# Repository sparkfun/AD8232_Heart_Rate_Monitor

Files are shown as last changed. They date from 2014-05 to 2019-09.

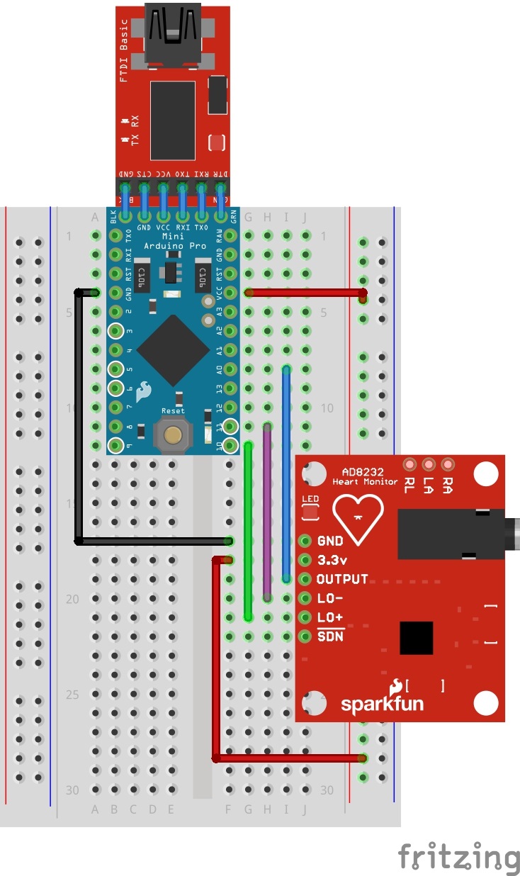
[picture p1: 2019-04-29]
Fritzing/AD8232_Heart_Rate_Monitor_Demo_bb_Fritzing_Corrected.jpg

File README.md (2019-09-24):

SparkFun AD8232 Single Lead Heart Rate Monitor
-------------------

AD8232 Breakout Board (https://www.sparkfun.com/products/12650)

[*AD8232 Single Lead Heart Rate Monitor (SEN-12650)*](https://www.sparkfun.com/products/12650)

The AD8232 is a neat little chip used to measure the electrical activity of the heart. This electrical activity can be charted as an ECG or Electrocardiogram. [Electrocardiography](http://en.wikipedia.org/wiki/Electrocardiography) is used to help diagnose various heart conditions. [The datasheet can be found here.](https://cdn.sparkfun.com/datasheets/Sensors/Biometric/AD8232.pdf)

This part was created in Eagle v6.5.0. 

Repository Contents
-------------------

* **/Fritzing** - Fritzing Example wiring images
* **/Hardware** - All Eagle design files (.brd, .sch)
* **/Production** - production panel files
* **/Software** - Demo program files for hookup guide

Documentation
--------------
* **[Hookup Guide](https://learn.sparkfun.com/tutorials/ad8232-heart-rate-monitor-hookup-guide/)** - Basic hookup guide AD8232 heart rate monitor.

Version History
---------------
* [v10](https://github.com/sparkfun/AD8232_Heart_Rate_Monitor/tree/v10) Initial Release

License Information
-------------------
The hardware is released under [Creative Commons Share-alike 3.0](http://creativecommons.org/licenses/by-sa/3.0/).  
All other code is open source so please feel free to do anything you want with it; you buy me a beer if you use this and we meet someday ([Beerware license](http://en.wikipedia.org/wiki/Beerware)).

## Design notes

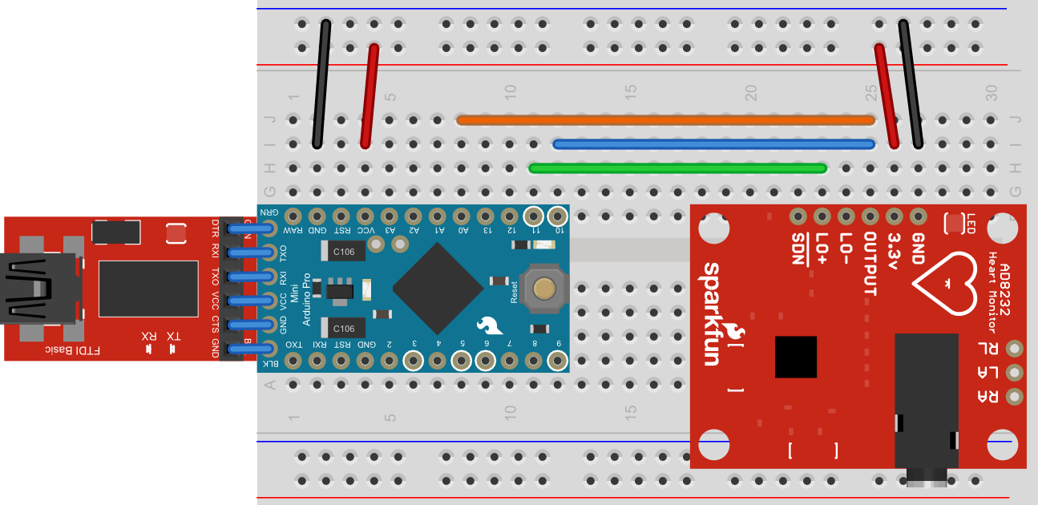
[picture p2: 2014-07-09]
Fritzing/Ad8232_Fritzing_Diagram.png

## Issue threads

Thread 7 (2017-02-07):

Not compatible with Processing 3.2.4

SSJJYY, 2017-02-07:
These codes cannot be operated on Processing 3.2.4 successfully. Only can on Processing 2.2.1.
Problems happens when you run it, it shows a blank display screen.
Can you update codes for version 3.2.4?
Thank you a lot.

paulio23, 2017-02-12:
Second that.

Fieryfire, 2017-02-13:
third that

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

mctosimaitb, 2017-02-16:
agree :)

ShubhaM220, 2017-03-08:
why is it not working on processing 3.2.4 ??

rubueh, 2017-04-30:
Ive made a pull request for the updated version of the heart rate monitor but have not gotten a response from Sparkfun. Here are some proposed changes for the code of the heart rate monitor, the old code could only function in the second version of Processing. The proposed changes now work for the newest version (3.3.2). I figured other individuals could benefit from this and help them get their project done faster and with a lot less headaches.

Side-Note

The only hiccup I encountered in modifying the code and comparing it to the old one's readings was that when it is supposed to be flat-line there is a negative charge that is registered, which was not there when run in Processing v2.
-RKB

Also let me know how it works for you.

//-----------------------------------New Code for Processing 3.2.+------------------//

/*
*  All rights reserved to the original creators.
*/

import processing.serial.*;

Serial myPort;
int xPos = 1;
float height_old = 0;
float height_new = 0;
float inByte = 0;

void setup () {
  //Window Size
  size(1080, 500);

  // List serial ports
  println(Serial.list());
  myPort = new Serial(this, Serial.list()[0], 9600);
  myPort.bufferUntil('\n');

  //Background
  background(255);

  fill(color(0,0,0));
  text("Heart Rate Monitor v1.0", 10, 10);
}

void draw () {

     inByte = map(inByte, 0, 1023, 0, height);
     height_new = height - inByte;
     line(xPos - 1, height_old, xPos, height_new);
     height_old = height_new;

      if (xPos >= width) {
        xPos = 0;
        background(255);
      }
      else {
        xPos++;
      }
}

void serialEvent (Serial myPort) {
  // get the ASCII string:
  String inString = myPort.readStringUntil('\n');

  if (inString != null) {
    // trim off any whitespace:
    inString = trim(inString);

    if (inString.equals("!")) {
      stroke(0, 0, 255);
      inByte = 512;
    }
    else {
      stroke(255, 0, 0);
      inByte = float(inString);
     }
  }
}

rubueh, 2017-04-30:
`//-----------------------------------New Code for Processing 3.2.+------------------//

/*
*  All rights reserved to the original creators.
*/

import processing.serial.*;

Serial myPort;
int xPos = 1;
float height_old = 0;
float height_new = 0;
float inByte = 0;

void setup () {
  //Window Size
  size(1080, 500);

  // List serial ports
  println(Serial.list());
  myPort = new Serial(this, Serial.list()[0], 9600);
  myPort.bufferUntil('\n');

  //Background
  background(255);

  fill(color(0,0,0));
  text("Heart Rate Monitor v1.0", 10, 10);
}

void draw () {

     inByte = map(inByte, 0, 1023, 0, height);
     height_new = height - inByte;
     line(xPos - 1, height_old, xPos, height_new);
     height_old = height_new;

      if (xPos >= width) {
        xPos = 0;
        background(255);
      }
      else {
        xPos++;
      }
}

void serialEvent (Serial myPort) {
  // get the ASCII string:
  String inString = myPort.readStringUntil('\n');

  if (inString != null) {
    // trim off any whitespace:
    inString = trim(inString);

    if (inString.equals("!")) {
      stroke(0, 0, 255);
      inByte = 512;
    }
    else {
      stroke(255, 0, 0);
      inByte = float(inString);
     }
  }
}`

XDTZ, 2017-05-01:
@rubueh I felt very lucky finishing my wiring and immediately finding your fix no longer than a day after you posted!
The code does work for me. However it seems serial plotter produce graph more clear than this. Thanks anyway!

rubueh, 2017-05-01:
@XDTZ I am glad the code was able to help and for getting back on how it works for you. If I can recommend something, while working on the wiring and programming I noticed my data was wonky while I had my charger plugged in to my laptop during testing. I then removed the charger and voila, it worked. So just double check your wiring or if you have an external power source that may be causing the interference, see if you can mend it. You may not need any extra items. Best of luck though!

marziacescon, 2017-05-31:
Hi!

I'm still having the blank screen problem, despite I'm running the fixed script proposed here..I don't know what I'm doing wrong! I feel discouraged. Any chance I could get any help here?

Thanks heaps!
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

Fieryfire, 2017-05-31:
Hi,

Do you see, if there is transmission through serial monitor?

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

marziacescon, 2017-06-01:
Hi! Thanks for your prompt reply! I'm new to this so not experienced at all!

How do you see if you get transmission? I mean: I can plot things on the
screen if I want to..just I can't visualize the ECG...

Marzia

On Wed, May 31, 2017 at 3:02 PM, Vivin Arikkudil <notifications@github.com>
wrote:

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

marziacescon, 2017-06-01:
Hi,

got it. I tried to modify that in order to allow communication, but nothing
happens still...

The ports are the following:

/dev/cu.Bluetooth-Incoming-Port /dev/cu.Bluetooth-Modem
/dev/cu.Cons-SerialPort
/dev/cu.usbserial-A904MJ7W /dev/tty.Bluetooth-Incoming-Port
/dev/tty.Bluetooth-Modem
/dev/tty.Cons-SerialPort /dev/tty.usbserial-A904MJ7W

Anything wrong in there?

Thanks again!

Marzia

On Wed, May 31, 2017 at 4:57 PM, Russell Buehling <notifications@github.com>
wrote:

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

marziacescon, 2017-06-01:
When I change port, I get the following error message (attached
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
)

rubueh, 2017-06-01:
@marziacescon
Hmmm first try checking all your wiring is correct, connect the ECG leads, run the sketch and see if can get a signal (even if its ugly one) from the leads just to make sure they are making contact and the wiring is correctly routing the signals. The other problem may be that if you have the Arduino program open, it is taking control of that port first to communicate with the Arduino itself. If so, just exit out, if not try to see what is taking up the communications port channel.

rubueh, 2017-06-01:
@marziacescon
I just realized your COM list simply looks different, so for every `/dev/` item you see, that is a different port. So the port you are wanting to communicate through may actually be `Serial.list()[5]` .

Fieryfire, 2017-06-02:
I think it says port busy because you are opening the serial monitor from
the arduino IDE as well. Let go of the the serial monitor and just let the
code from processing run

On Thu, Jun 1, 2017 at 5:21 PM, Russell Buehling <notifications@github.com>
wrote:

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

njay96, 2017-06-04:
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
@rubueh im so happy when ur code work for me, thank you. but, my result so noisy. how to calibrate it? or it because wrong placement of the sensor. i so confused if it by sensor placement, im affraid if i not correctly put that sensor. sorry my english so bad. anyway, thank you!

marziacescon, 2017-06-04:
Hi!

Thank you for your suggestions.

I'm afraid to say, I still have the same problem.

* I'm letting the code from Processing only run (no Arduino)
* I have identified the correct port, i.e., I don't get the "port busy"
message anymore.

But I still have only a blank screen...like no signals is going through.
I've check the wiring as well and it seems correct...What shall I do now?

Thank you in advance!

Marzia

On Fri, Jun 2, 2017 at 9:09 AM, Vivin Arikkudil <notifications@github.com>
wrote:

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

marziacescon, 2017-06-04:
I'm thinking that maybe the AD8232 is faulty....

Marzia

On Fri, Jun 2, 2017 at 9:09 AM, Vivin Arikkudil <notifications@github.com>
wrote:

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

rubueh, 2017-06-04:
@marziacescon

I'm thinking it might be as well, if not ask someone else to double check everything as a last resort and no problem, I really do hope you can get it to work.

marziacescon, 2017-06-04:
I do hope it as well.

I got already someone checking the wiring : it seems all is good. So i
think the sensor might be faulty.

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

Fieryfire, 2017-06-04:
Does the serial port from the arduino IDE run any values to the the monitor?

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

marziacescon, 2017-06-05:
Actually not. No numbers. It's so frustrating!

Marzia

On Sun, Jun 4, 2017 at 11:33 PM, Vivin Arikkudil <notifications@github.com>
wrote:

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

Fieryfire, 2017-06-05:
Using a multimeter, are you able to get any sort of readings from the
analog output?

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

marziacescon, 2017-06-05:
Hi!

I'm going to borrow one as soon as I can.

In the meantime, I checked if the Arduino and Processing were able to
communicate. I used the following scripts:

***arduino***
**************
void setup()
{
//initialize serial communications at a 9600 baud rate
Serial.begin(9600);
}

void loop()
{
//send 'Hello, world!' over the serial port
Serial.println("Hello, world!");
//wait 100 milliseconds so we don't drive ourselves crazy
delay(100);
}

***processing***
******************
import processing.serial.*;
Serial myPort;  // Create object from Serial class
String val;     // Data received from the serial port
void setup()
{
  // I know that the first port in the serial list on my mac
  // is Serial.list()[0].
  // On Windows machines, this generally opens COM1.
  // Open whatever port is the one you're using.
  String portName = Serial.list()[0]; //change the 0 to a 1 or 2 etc. to
match your port
  myPort = new Serial(this, portName, 9600);
}
void draw()
{
  if ( myPort.available() > 0)
  {  // If data is available,
  val = myPort.readStringUntil('\n');         // read it and store it in val
  }
println(val); //print it out in the console
}

****

And what I get out printed in the console is:
null
null
null
...

Do it seems that the Arduino is not talking to processing..maybe why I
don't get any signal displayed. I swear, I followed the instructions
literally and I'm not getting it to work! I thought I was going to learn
things, instead I'm getting demoralised.

Marzia

On Mon, Jun 5, 2017 at 7:12 PM, Vivin Arikkudil <notifications@github.com>
wrote:

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

marziacescon, 2017-06-05:
And this is what I get on the serial monitor
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

Fieryfire, 2017-06-06:
Lets trouble shoot it step by step, the serial terminal from the arduino
IDE shows you the above results? am i correct? it means there is something
wrong from the arduino side itself.

1)Try the code using another system, windows (preferably?)
2)set the port of the arduino to be the same as the one in serial monitor.
3) Show more screenshots on your setup and lets see whats going.

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

marziacescon, 2017-06-06:
Let's do it. I really appreciate your patience! Thanks.

So:
1) I have tried the code on a Windows machine
2) The port of the Arduino is the same of the serial monitor, i.e., COM3 (see pics)
3) I am attaching some pics of the results and the setup.

Hopefully we'll be able to sort things out.
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

Fieryfire, 2017-06-06:
1) Try just outputing the hello world alone to serial. Show the result. If
the basic hello world serial out fails to work. You should first
troubleshoot this stage.
2) From the circuit wiring . Make sure to connect output of AD8232 to A0 of
arduino board. Also is the arduino a 3.3v or a 5v??? Because the AD8232 is
not 5V tolerant.
3) Make sure that when the FTDI is connected in the right direction, VCC
->VCC GND to GND,etc... Share the the pin layout of the arduino you are
using.

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

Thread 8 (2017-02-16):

Classify Wave into PQRST

mctosimaitb, 2017-02-16:
Hi, i just have an idea. What if the wave is classified into PQRST wave intervals, such as 'p wave', 'QRS Complex', and 't wave', etc. The goal is that the system can recognize that there are abnormalities of the heart such as heart attacks. Do you have a way to do that?

Fieryfire, 2017-02-16:
Hi Yes, this can be done by adding elements to the software. But do realize
that this isnt completely medically accurate. and we would need to use
medical grade equipments. This is more for hobbyists to play around with
heart rates

On Thu, Feb 16, 2017 at 6:27 AM, Martin Manullang <notifications@github.com>
wrote:

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

mctosimaitb, 2017-04-09:
could u tell me, what is the lowest number and the highest number that displayed in serial monitor when using ad8232 ?

I just want to imagine how to implement those number into ecg block paper..

Grahldg, 2018-07-16:
Hello mctosimaitb,

These values can vary significantly depending on where the electrodes are connected and from person to person.  It may be possible to normalize the data and use algorithms to identify different wave forms, but that is beyond the scope of the example provided here.  You might find the [datasheet](https://cdn.sparkfun.com/datasheets/Sensors/Biometric/AD8232.pdf) helpful.  In addition our [Technical Support Team](https://www.sparkfun.com/technical_assistance) can help with any further questions you may have.

Thanks,
Sam

Closed 2018-07-16.

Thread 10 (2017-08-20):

Calculating BPM

beingmachine, 2017-08-20:
Hello,
I have https://www.sparkfun.com/products/12650 AD8232 board, from which i can use to plot heart rate PQRST data, however  i can't see code for calculating BPM from the peak like the pulse sensor code do.

How can i calculate BPM with this board

I am getting this output at my Serial Plotter in Arduino..

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

Please help

Thank you

jawhra, 2017-12-16:
Hello,
please I am a student and I am working on the same project could you help me to get the same output , I really need the correct code .
Thanks ,I appreciate your help .

beingmachine, 2017-12-16:
Hello Jawhra,
Can you post your code.? and what you want to achieve ,Of course i will help you with this.

Grahldg, 2018-07-16:
BPM calculation example has been added to the Processing sketch [here](https://github.com/sparkfun/AD8232_Heart_Rate_Monitor/blob/master/Software/Heart_Rate_Display_Processing/Heart_Rate_Display/Heart_Rate_Display.pde).

Chininha, 2020-10-01:
@Grahldg Do you if this code of the Programming that you sent is compatible with this code:

`void setup() {
// initialize the serial communication:
Serial.begin(9600);
pinMode(10, INPUT); // Setup for leads off detection LO +
pinMode(11, INPUT); // Setup for leads off detection LO -

}

void loop() {

if((digitalRead(10) == 1)||(digitalRead(11) == 1)){
Serial.println('!');
}
else{
// send the value of analog input 0:
Serial.println(analogRead(A1));
}
//Wait for a bit to keep serial data from saturating
delay(10);
}`

Chininha, 2020-10-01:
I'm doing a project with the sensor AD8232 and I want to see the BMP, but this kind of sensor doesn't do it. Do you know if there is a way to do it?

Closed 2018-07-16.

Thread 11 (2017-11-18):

Sensor returning only '!'

MatheusCastilho2, 2017-11-18:
Hi, everyone.  I need this project for 3 days....

In condition below always return '!'

if ((digitalRead (10) == 1) || (digitalRead (11) == 1))
  { Serial.println ('!'); }
  else
  {
    Serial.println(analogRead (A0));

    }
    delay (1);

How I resolve this?

harpekar, 2018-04-15:
I have filed an issue to fix this (#12).

Grahldg, 2018-07-16:
I was unable to duplicate this issue with the circuit described in the hookup guide.  If you are having issues in the future and need more immediate assistance, please contact our [Technical Support Team](https://www.sparkfun.com/technical_assistance).

Closed 2018-07-16.

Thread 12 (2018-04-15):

SDN Pin missing from initialization

harpekar, 2018-04-15:
The SDN pin must be pulled high in order for the board to not be put into Shutdown mode, as stated in the [datasheet](http://www.analog.com/media/en/technical-documentation/data-sheets/AD8232.pdf) on page 19.

Recommend adding

```c++
pinMode(SDNBAR, INPUT);
digitalWrite(SDNBAR, HIGH);
```

in `setup()`, with SDNBAR being the Arduino pin that indexes SDN.

vredzhepov, 2018-05-30:
The SDN pin has been already pulled up by R15 so there's no need to pull it up in code.

Grahldg, 2018-07-16:
Thank you for your suggestion.  This does not seem to affect the functionality of the circuit described in the hookup guide.  If you are still having issues with this and have further questions, please contact our [Technical Support Team](https://www.sparkfun.com/technical_assistance).

Closed 2018-07-16.

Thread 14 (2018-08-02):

Sampling rate

DominiqueMakowski, 2018-08-02:
Hey, I do have a question and didn't find the answer in the data sheet.

What is the default / maximum sampling rate with which we can acquire ECG with this?

Thanks

Fieryfire, 2018-08-02:
You essentially find the bandwidth of the ECG signal and multiply by 10. So
you have 40Hz bandwidth. And with 400Hz set as sampling rate. You should be
good to go

On Thu, Aug 2, 2018 at 4:08 PM, Dominique Makowski <notifications@github.com
> wrote:

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

Fieryfire, 2018-08-03:
The AD8232 is only a signal conditioner. The output from it is analog. It
is upto you to use a micro controller with an ADC to be able to sample the
analog data
For ex. using an arduino can get the job done

On Thu, Aug 2, 2018 at 6:23 PM, Dominique Makowski <notifications@github.com
> wrote:

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

DominiqueMakowski, 2018-08-03:
Ok i got it  :)

Closed 2018-08-03.

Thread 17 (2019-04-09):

Processing about AD8232

Crazychaochao, 2019-04-09:
When i use the code of AD8232 -Heart_Rate_Display,it got a problem like this "**ArrayIndexOutOfBoundsException: 2**"
the error code is   " myPort = new Serial(this, Serial.list()[2], 9600); "
I have try to modify it,for example  0,1,2.my computer COM is 3,but it doesn’t matter

Crazychaochao, 2019-04-09:
I don't know if anyone can help me

yongjun94, 2019-04-12:
How about change your code like this?
I solved the same problem. using this.

--------------------------------------------------------
Before code
  myPort = new Serial(this, Serial.list()[2], 9600);

After code
  myPort = new Serial(this, Serial.list()[0], 9600);

Crazychaochao, 2019-04-12:
Sincerely thanks! I have solved the problem by another way.
I will get back to you later on how i solved it ,because now it's got a new problem.So embarrassing!
My English is limited,thanks again

------------------ 原始邮件 ------------------
发件人: "yongjun94"<notifications@github.com>;
发送时间: 2019年4月12日(星期五) 中午1:54
收件人: "sparkfun/AD8232_Heart_Rate_Monitor"<AD8232_Heart_Rate_Monitor@noreply.github.com>;
抄送: "邓新潮"<838338194@qq.com>; "Author"<author@noreply.github.com>;
主题: Re: [sparkfun/AD8232_Heart_Rate_Monitor] Processing about AD8232(#17)

How about change your code like this?
 I solved the same problem. using this.

Before code
 myPort = new Serial(this, Serial.list()[2], 9600);

After code
 myPort = new Serial(this, Serial.list()[0], 9600);

—
You are receiving this because you authored the thread.
Reply to this email directly, view it on GitHub, or mute the thread.

Crazychaochao, 2019-04-21:
`import processing.serial.*;

  Serial myPort;        // The serial port
  int xPos = 1;         // horizontal position of the graph
  float inByte = 0;

  int beat_old = 0;
  int BPM = 0;
  int beatIndex;
  float[] beats = new float[500];  // Used to calculate average BPM

  void setup () {
    // set the window size:
    size(600, 700);

    // List all the available serial ports
    // if using Processing 2.1 or later, use Serial.printArray()
    println(Serial.list());

    // I know that the first port in the serial list on my Mac is always my
    // Arduino, so I open Serial.list()[0].
    // Open whatever port is the one you're using.
    myPort = new Serial(this, Serial.list()[0], 9600);

    // don't generate a serialEvent() unless you get a newline character:
    myPort.bufferUntil('\n');

    // set initial background:
    background(0);
  }

  void draw () {
    // draw the line:
    stroke(127, 34, 255);
    line(xPos, height, xPos, height - inByte);

    // at the edge of the screen, go back to the beginning:
    if (xPos >= width) {
      xPos = 0;
      background(0);
    } else {
      // increment the horizontal position:
      xPos++;
    }
  }

  void serialEvent (Serial myPort) {
    // get the ASCII string:
    String inString = myPort.readStringUntil('\n');

    if (inString != null) {
      // trim off any whitespace:
      inString = trim(inString);
      // convert to an int and map to the screen height:
      inByte = float(inString);
      println(inByte);
      inByte = map(inByte, 0, 1023, 0, height);
    }
  }`

this is the final code

bboyho, 2019-04-29:
Hi,

I was updating the tutorial when I noticed your question in the GitHub repo. In case you were wondering, the error that you are seeing in the Processing IDE is probably due to the number of COM ports that are available on your computer:

    ArrayIndexOutOfBoundsException: 2

You will need to look at the list of available COM ports and adjust the array number. The case shown in the tutorial shows that the Arduino enumerated on "**COM 38**" for the author's computer. Counting each COM port from 0 (in terms of programming not in mathematical terms) from left to right. this is listed as element "**2**".

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

As far as the new problem, I am not entirely sure what the issue since you did not provide enough information on the problem? You only provided your modified code which is missing certain functions that were used in the example code => [ [https://github.com/sparkfun/AD8232_Heart_Rate_Monitor/blob/master/Software/Heart_Rate_Display_Processing/Heart_Rate_Display/Heart_Rate_Display.pde](https://github.com/sparkfun/AD8232_Heart_Rate_Monitor/blob/master/Software/Heart_Rate_Display_Processing/Heart_Rate_Display/Heart_Rate_Display.pde) ]. You might want to post in one of the following forums for further assistance.

* [SparkFun Forums](https://forum.sparkfun.com/viewforum.php?f=143)
* [Processing Forums](https://discourse.processing.org/)

Crazychaochao, 2019-05-15:
So sorry to get back so late.I have solved the problem I met，and Thank you very much for your noticed.Sincerely thank you！

------------------ 原始邮件 ------------------
发件人: "bboyho"<notifications@github.com>;
发送时间: 2019年4月30日(星期二) 凌晨2:40
收件人: "sparkfun/AD8232_Heart_Rate_Monitor"<AD8232_Heart_Rate_Monitor@noreply.github.com>;
抄送: "邓新潮"<838338194@qq.com>;"Author"<author@noreply.github.com>;
主题: Re: [sparkfun/AD8232_Heart_Rate_Monitor] Processing about AD8232(#17)

Hi,

I was updating the tutorial when I noticed your question in the GitHub repo. In case you were wondering, the error that you are seeing in the Processing IDE is probably due to the number of COM ports that are available on your computer:
 ArrayIndexOutOfBoundsException: 2
You will need to look at the list of available COM ports and adjust the array number. The case shown in the tutorial shows that the Arduino enumerated on "COM 38" for the author's computer. Counting each COM port from 0 (in terms of programming not in mathematical terms) from left to right. this is listed as element "2".

As far as the new problem, I am not entirely sure what the issue since you did not provide enough information on the problem? You only provided your modified code which is missing certain functions that were used in the example code => [ https://github.com/sparkfun/AD8232_Heart_Rate_Monitor/blob/master/Software/Heart_Rate_Display_Processing/Heart_Rate_Display/Heart_Rate_Display.pde ]. You might want to post in one of the following forums for further assistance.

SparkFun Forums

Processing Forums

—
You are receiving this because you authored the thread.
Reply to this email directly, view it on GitHub, or mute the thread.

Closed 2019-04-29.

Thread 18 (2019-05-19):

port not found

preksha02, 2019-05-19:
hello
i am using a ad8232 interfacing with arduino uno. The output generated in serial monitor is fine but the when i tried it in processing, its not working. there is a error in 1 line i.e. myPort = new Serial(this, Serial.list()[2], 9600);
According to the text i read, serial.list()[2], here 2 signifies the serial port, but when i write 2 it shows an error 'ArrayIndexOutOfBoundsException: 2'
i dont know to to resolve it . Kindly help

bboyho, 2019-09-24:
Hi,

I just saw your comment. The number of ports that show up depends on your computer. You will need to change the parameter inside `Serial.list()[N]` based on the enumerated COM ports on your computer. A list of available COM ports will appear in the lower portion of the sketch window. Remember that COM port selection begins at `0` so you would be counting each COM port from `0 `(in terms of programming not in mathematical terms) from left to right. In this case, the Arduino enumerated as `COM38` when uploading so it should be in the 3rd element in the array. Therefore, you would change the value to `2`. As a result, the example code would be listed as `Serial.list()[2]`. Typically your Arduino will appear as the highest COM number if it is the only device connected to your computer.

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

If your computer is showing three COM ports above, it's possible that there is another process that is using the COM port (i.e. your Arduino Serial Monitor). Make sure to close out any windows that are utilizing the resource.

Closed 2019-09-24.

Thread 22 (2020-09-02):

this is not a good chip for measuring biosignals

phpkadir, 2020-09-02:
this chip dont have digital data handlers. its datasheet has not any analog to digital converters. this chip is an opamp only.
you should choose  ti-ads1262 to measure a biosignal. its giving digital measurement data to microcontrollers. ti ads1262 has all diferential inputs. who use this mistaken chip is an misguide guru.

vredzhepov, 2020-09-29:
The AD8232 is an integrated signal conditioning block for ECG and other biopotential measurement applications. It is designed
to extract, amplify, and filter small biopotential signals in the presence of noisy conditions, such as those created by motion
or remote electrode placement. This design allows for an ultralow power analog-to-digital converter (ADC) or an embedded microcontroller to acquire the output signal easily.

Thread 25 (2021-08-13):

Is it possible to add filtering specifications?

matteoscrugli, 2021-08-13:
Hello,
thanks for your work, I was wondering if it was possible to add the specifications of the High-pass and Low-pass filters (for example the cut-off frequency) to the Readme of the repository (or where you want). Through the schematic you have released and the AD8232 datasheet is it possible to calculate them, but it is not very comfortable for users. Thank you very much.

franzbischoff, 2025-08-27:
Use this example with a 50hz filter:

```cpp
#include <Arduino.h>

#define LO_PLUS 4
#define LO_MINUS 5

// 50 Hz Notch and sampling timing
const uint16_t FS_HZ = 1000; // fixed sampling rate [Hz]
const float F_NOTCH = 50.0f; // change to 60.0f if needed
const float Q_NOTCH = 30.0f; // higher = narrower band

// Normalized coefficients (RBJ) and biquad states
float b0n, b1n, b2n, a1n, a2n;
// rename states to avoid conflict with y0()/y1() from math.h
float x1 = 0, x2 = 0, y_prev1 = 0, y_prev2 = 0;

uint32_t sampleIntervalUs;
uint32_t nextSampleUs;

static void initNotch()
{
  float w0 = 2.0f * PI * F_NOTCH / FS_HZ;
  float cw = cos(w0);
  float alpha = sin(w0) / (2.0f * Q_NOTCH);
  float a0 = 1.0f + alpha;

  // bandstop (notch) RBJ, normalized by a0
  b0n = 1.0f / a0;
  b1n = (-2.0f * cw) / a0;
  b2n = 1.0f / a0;
  a1n = (-2.0f * cw) / a0;
  a2n = (1.0f - alpha) / a0;
}

// Utility function to send 1+ values (uint32_t) in a binary frame
static inline void sendFrame(const uint32_t *values, uint8_t count)
{
  // Start marker (2 bytes)
  Serial.write(0xAA);
  Serial.write(0x88);

  uint8_t checksum = 0;

  // Values (4 bytes each) + checksum
  for (uint8_t i = 0; i < count; ++i)
  {
    uint32_t v = values[i];
    Serial.write((uint8_t *)&v, sizeof(uint32_t));
    uint8_t *vb = (uint8_t *)&v;
    for (int b = 0; b < 4; ++b)
      checksum += vb[b];
  }

  Serial.write(checksum);
}

void setup()
{
  // initialize the serial communication:
  // Increase UART throughput
  Serial.setTxBufferSize(4096); // ESP32: larger buffer reduces blocking
  Serial.begin(115200);
  pinMode(LO_PLUS, INPUT);  // Setup for leads off detection LO +
  pinMode(LO_MINUS, INPUT); // Setup for leads off detection LO -
  // Sampling scheduler + notch init
  sampleIntervalUs = 1000000UL / FS_HZ;
  nextSampleUs = micros() + sampleIntervalUs;
  initNotch();
}

void loop()
{
  // Executes at the fixed rate FS_HZ
  if ((int32_t)(micros() - nextSampleUs) >= 0)
  {
    nextSampleUs += sampleIntervalUs;

    if ((digitalRead(LO_PLUS) == 1) || (digitalRead(LO_MINUS) == 1))
    {
      // Reset states to avoid transients while electrodes are off
      x1 = x2 = y_prev1 = y_prev2 = 0;
      // Send frame with zeros (raw=0, filtered=0)
      uint32_t payload[2] = {0u, 0u};
      sendFrame(payload, 2);
    }
    else
    {
      // Sample, filter (50 Hz notch), and send
      int raw = analogRead(A0);
      float x0 = (float)raw;
      float y_curr = b0n * x0 + b1n * x1 + b2n * x2 - a1n * y_prev1 - a2n * y_prev2;
      x2 = x1;
      x1 = x0;
      y_prev2 = y_prev1;
      y_prev1 = y_curr;

      // Clip to [0, 4095] before packing as uint32
      int32_t y_i = (int32_t)y_curr;
      if (y_i < 0) y_i = 0;
      if (y_i > 4095) y_i = 4095;

      uint32_t payload[2] = { (uint32_t)raw, (uint32_t)y_i };
      sendFrame(payload, 2);
    }
  }
}
```

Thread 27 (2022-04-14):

ECG Two Electrode Mode

GkekasK, 2022-04-14:
Hello Sparkfun-team,

I purchased the "SparkFun Single Lead Heart Rate Monitor - AD8232" and I want to use the "two electrode mode" as mentioned in the [datasheet](https://cdn.sparkfun.com/datasheets/Sensors/Biometric/AD8232.pdf) in the following captions "Right Leg Drive Amplifier", "AC Leads Off Detection" and "Heart Rate Measurement Next to the Heart". How can I activate this mode? How can I extract the RL/RLD Pin in order to use only the RA and LA Pin?

Thank you very much for you help and time in advance

Best regards

Kosta

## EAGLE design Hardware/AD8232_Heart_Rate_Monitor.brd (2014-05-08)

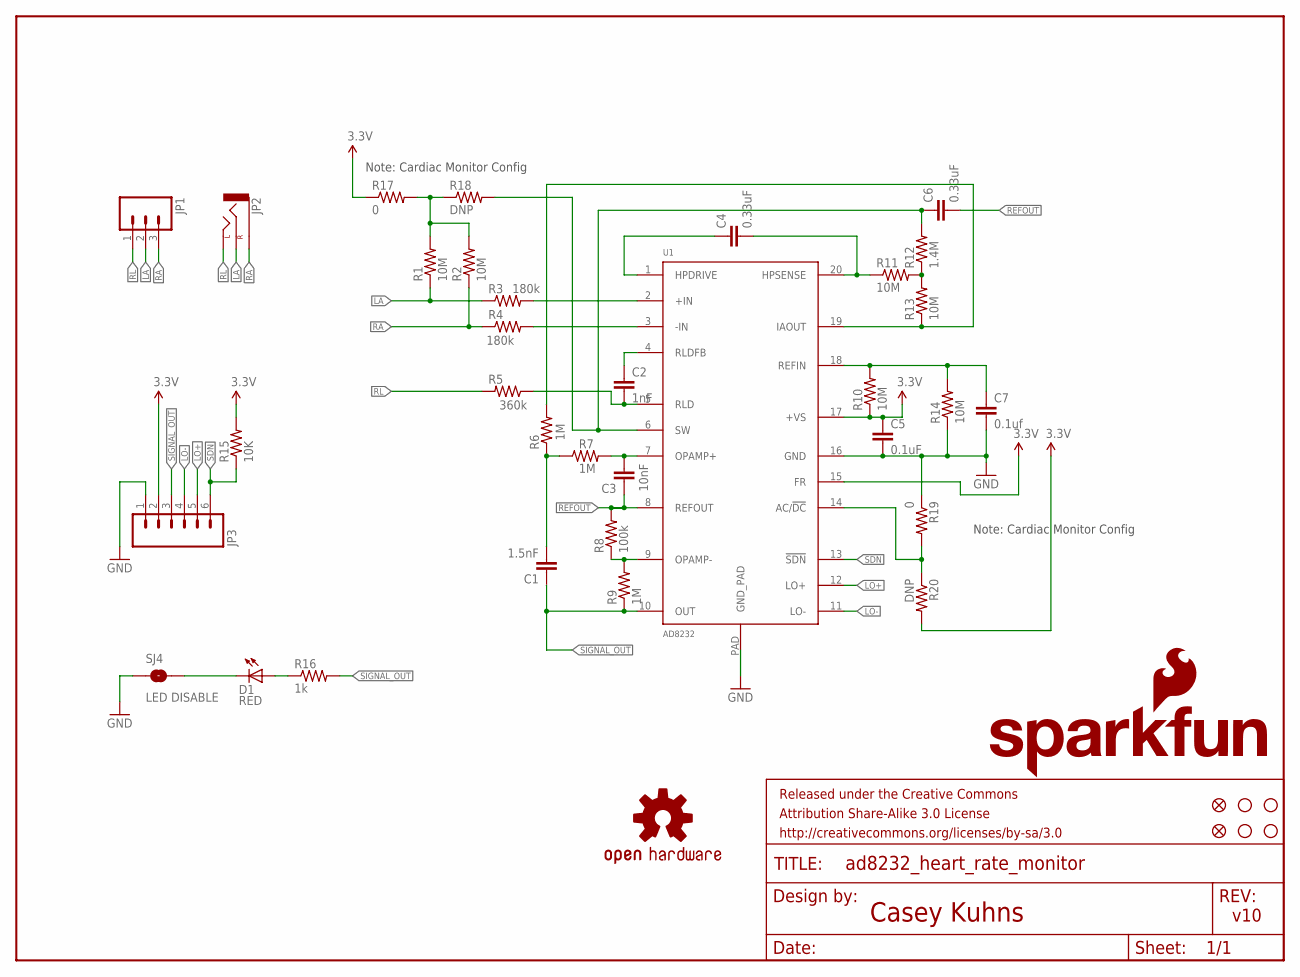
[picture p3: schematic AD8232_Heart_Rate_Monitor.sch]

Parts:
C1: 1.5nF; 0603-CAP
C2: 1nF; 0603-CAP
C3: 10nF; 0603-CAP
C4, C6: 0.33uF; 0805
C5: 0.1uF; 0603-CAP
C7: 0.1uf; 0603-CAP
D1: RED; LED-0603
FID1, FID2: FIDUCIAL1X2; FIDUCIAL-1X2
FRAME1: FRAME-LETTER; CREATIVE_COMMONS
JP1: M03PTH; 1X03
JP2: AUDIO-JACKSMD2; AUDIO-JACK-3.5MM-SMD
JP3: M06SIP; 1X06
LOGO1: OSHW-LOGOS; OSHW-LOGO-S
LOGO2: SFE_LOGO_NAME_FLAME.1_INCH; SFE_LOGO_NAME_FLAME_.1
R1, R2, R10, R11, R13, R14: 10M; 0603-RES
R3, R4: 180k; 0603-RES
R5: 360k; 0603-RES
R6, R7, R9: 1M; 0603-RES
R8: 100k; 0603-RES
R12: 1.4M; 0603-RES
R15: 10K; 0603-RES
R16: 1k; 0603-RES
R17, R19: 0; 0603
R18, R20: DNP; 0603
SJ4: LED DISABLE; SJ_2S-TRACE
STANDOFF1, STANDOFF2, STANDOFF3, STANDOFF4: STAND-OFF
U1: AD8232; LFCSP_20

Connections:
3.3V: C5.1, JP3.2, R10.1, R15.2, R17.1, R20.2, U1.15 (FR), U1.17 (+VS)
GND: C5.2, C7.2, JP3.1, R14.1, R19.1, SJ4.1, U1.16 (GND), U1.PAD (GND_PAD)
LA: JP1.2, JP2.RING (RIGHT), R1.1, R3.1
LO+: JP3.5, U1.12 (LO+)
LO-: JP3.4, U1.11 (LO-)
unnamed: R3.2, U1.2 (+IN)
unnamed: R4.2, U1.3 (-IN)
unnamed: C3.2, R7.2, U1.7 (OPAMP+)
unnamed: C4.2, R11.1, U1.20 (HPSENSE)
unnamed: C7.1, R10.2, R14.2, U1.18 (REFIN)
unnamed: D1.A, R16.1
unnamed: R8.1, R9.2, U1.9 (OPAMP-)
unnamed: R6.2, R13.1, U1.19 (IAOUT)
unnamed: C1.2, R6.1, R7.1
unnamed: D1.C, SJ4.2
unnamed: R19.2, R20.1, U1.14 (AC/!DC)
unnamed: C4.1, U1.1 (HPDRIVE)
unnamed: R11.2, R12.1, R13.2
unnamed: C6.1, R12.2, R18.2, U1.6 (SW)
unnamed: C2.1, U1.4 (RLDFB)
unnamed: C2.2, R5.1, U1.5 (RLD)
unnamed: R1.2, R2.2, R17.2, R18.1
RA: JP1.3, JP2.SLEEVE, R2.1, R4.1
REFOUT: C3.1, C6.2, R8.2, U1.8 (REFOUT)
RL: JP1.1, JP2.TIP (LEFT), R5.2
SDN: JP3.6, R15.1, U1.13 (!SDN)
SIGNAL_OUT: C1.1, JP3.3, R9.1, R16.2, U1.10 (OUT)

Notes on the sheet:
Casey Kuhns
v10
Note: Cardiac Monitor Config

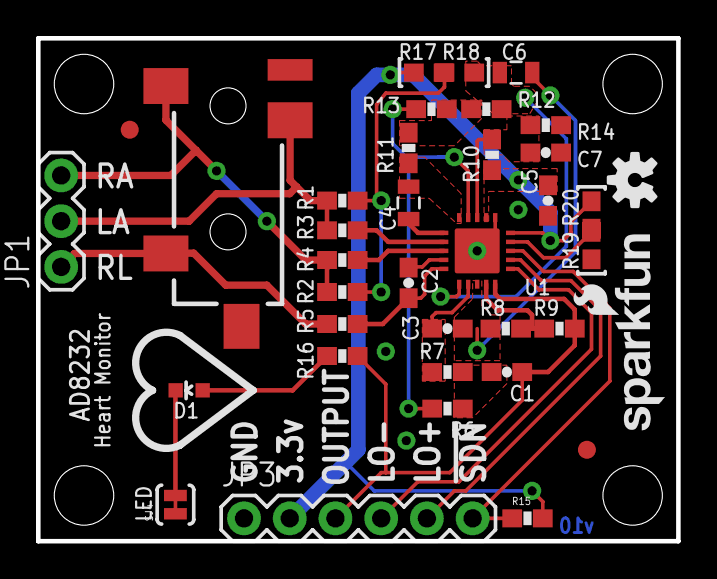
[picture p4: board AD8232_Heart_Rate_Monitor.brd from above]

Board: 2 copper layers, 35.6 x 27.9 mm, 42 parts (0 on the bottom side), 27 nets.

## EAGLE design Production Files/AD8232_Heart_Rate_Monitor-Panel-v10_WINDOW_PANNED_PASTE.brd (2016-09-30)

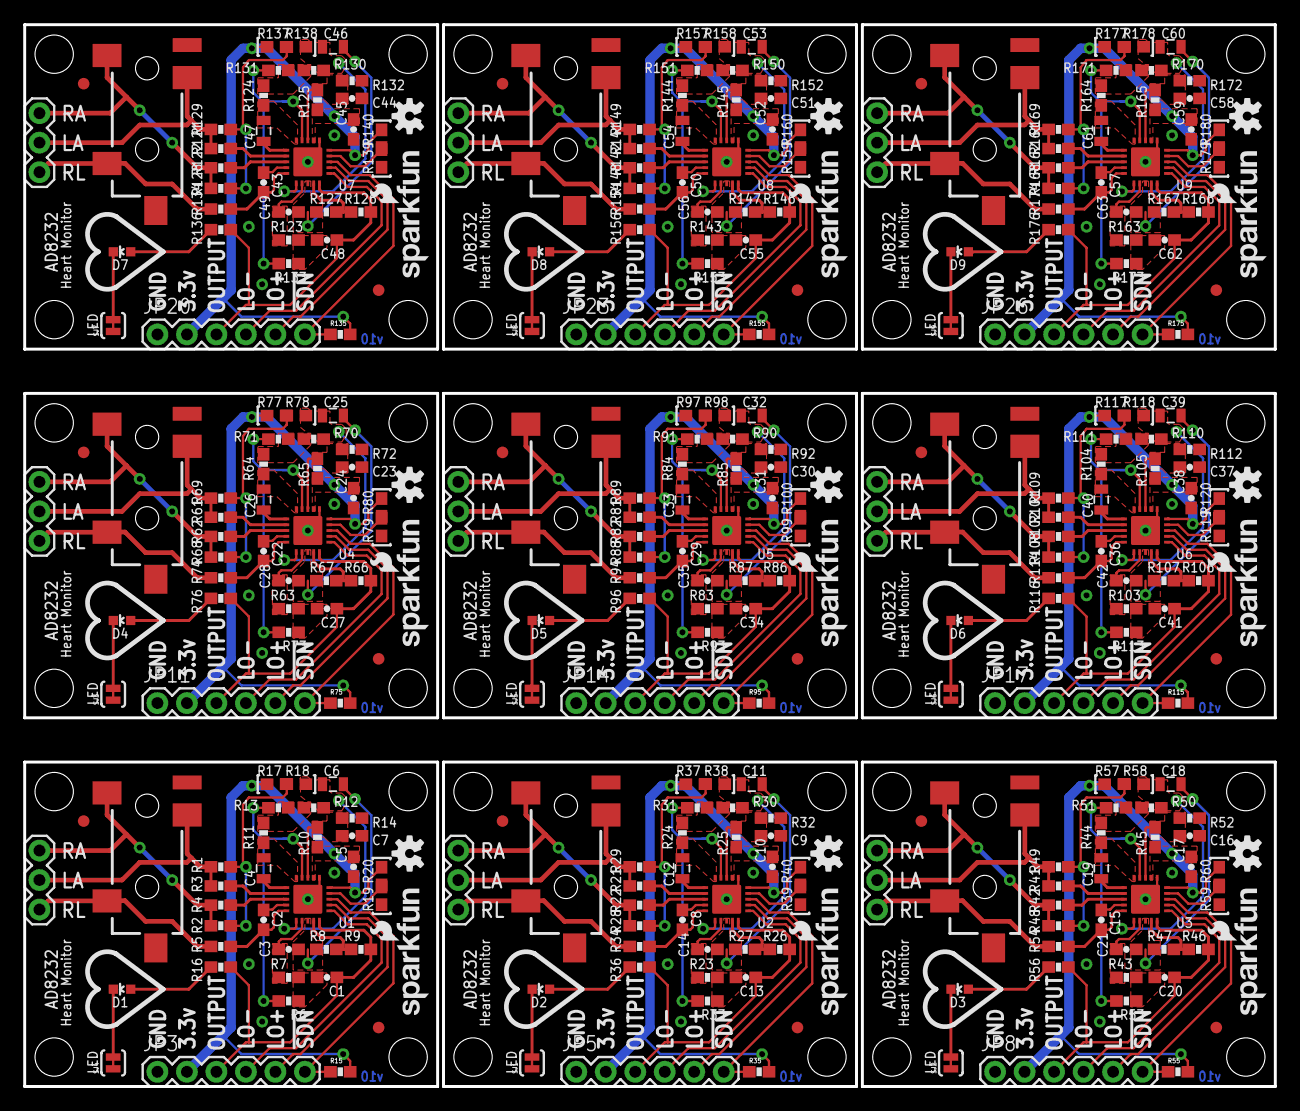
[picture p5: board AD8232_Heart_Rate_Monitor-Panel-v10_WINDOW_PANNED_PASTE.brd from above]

Board: 2 copper layers, 107.7 x 91.4 mm, 369 parts (0 on the bottom side), 243 nets.

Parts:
C1, C13, C20, C27, C34, C41, C48, C55, C62: 1.5nF; 0603-CAP
C2, C8, C15, C22, C29, C36, C43, C50, C57: 1nF; 0603-CAP
C3, C14, C21, C28, C35, C42, C49, C56, C63: 10nF; 0603-CAP
C4, C6, C11, C12, C18, C19, C25, C26, C32, C33, C39, C40, C46, C47, C53, C54, C60, C61: 0.33uF; 0805
C5, C10, C17, C24, C31, C38, C45, C52, C59: 0.1uF; 0603-CAP
C7, C9, C16, C23, C30, C37, C44, C51, C58: 0.1uf; 0603-CAP
D1, D2, D3, D4, D5, D6, D7, D8, D9: RED; LED-0603
FID1, FID2, FID3, FID4, FID5, FID6, FID7, FID8, FID9, FID10, FID11, FID12, FID13, FID14, FID15, FID16, FID17, FID18: FIDUCIAL1X2; FIDUCIAL-1X2
JP1, JP6, JP9, JP12, JP15, JP18, JP21, JP24, JP27: 1X03
JP2, JP4, JP7, JP10, JP13, JP16, JP19, JP22, JP25: AUDIO-JACK-3.5MM-SMD
JP3, JP5, JP8, JP11, JP14, JP17, JP20, JP23, JP26: 1X06
LOGO1, LOGO4, LOGO6, LOGO8, LOGO10, LOGO12, LOGO14, LOGO16, LOGO18: OSHW-LOGOS; OSHW-LOGO-S
LOGO2, LOGO3, LOGO5, LOGO7, LOGO9, LOGO11, LOGO13, LOGO15, LOGO17: SFE_LOGO_NAME_FLAME.1_INCH; SFE_LOGO_NAME_FLAME_.1
R1, R2, R10, R11, R13, R14, R24, R25, R28, R29, R31, R32, R44, R45, R48, R49, R51, R52, R64, R65, R68, R69, R71, R72, R84, R85, R88, R89, R91, R92, R104, R105, R108, R109, R111, R112, R124, R125, R128, R129, R131, R132, R144, R145, R148, R149, R151, R152, R164, R165, R168, R169, R171, R172: 10M; 0603-RES
R3, R4, R21, R22, R41, R42, R61, R62, R81, R82, R101, R102, R121, R122, R141, R142, R161, R162: 180k; 0603-RES
R5, R34, R54, R74, R94, R114, R134, R154, R174: 360k; 0603-RES
R6, R7, R9, R23, R26, R33, R43, R46, R53, R63, R66, R73, R83, R86, R93, R103, R106, R113, R123, R126, R133, R143, R146, R153, R163, R166, R173: 1M; 0603-RES
R8, R27, R47, R67, R87, R107, R127, R147, R167: 100k; 0603-RES
R12, R30, R50, R70, R90, R110, R130, R150, R170: 1.4M; 0603-RES
R15, R35, R55, R75, R95, R115, R135, R155, R175: 10K; 0603-RES
R16, R36, R56, R76, R96, R116, R136, R156, R176: 1k; 0603-RES
R17, R19, R37, R39, R57, R59, R77, R79, R97, R99, R117, R119, R137, R139, R157, R159, R177, R179: 0; 0603
R18, R20, R38, R40, R58, R60, R78, R80, R98, R100, R118, R120, R138, R140, R158, R160, R178, R180: DNP; 0603
SJ1, SJ2, SJ3, SJ4, SJ5, SJ6, SJ7, SJ8, SJ9: LED DISABLE; SJ_2S-TRACE
STANDOFF1, STANDOFF2, STANDOFF3, STANDOFF4, STANDOFF5, STANDOFF6, STANDOFF7, STANDOFF8, STANDOFF9, STANDOFF10, STANDOFF11, STANDOFF12, STANDOFF13, STANDOFF14, STANDOFF15, STANDOFF16, STANDOFF17, STANDOFF18, STANDOFF19, STANDOFF20, STANDOFF21, STANDOFF22, STANDOFF23, STANDOFF24, STANDOFF25, STANDOFF26, STANDOFF27, STANDOFF28, STANDOFF29, STANDOFF30, STANDOFF31, STANDOFF32, STANDOFF33, STANDOFF34, STANDOFF35, STANDOFF36: STAND-OFF
U1, U2, U3, U4, U5, U6, U7, U8, U9: AD8232; LFCSP_20

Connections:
3.3V: C5.1, JP3.2, R10.1, R15.2, R17.1, R20.2, U1.15, U1.17
3.3V1: C10.1, JP5.2, R25.1, R35.2, R37.1, R40.2, U2.15, U2.17
3.3V2: C17.1, JP8.2, R45.1, R55.2, R57.1, R60.2, U3.15, U3.17
3.3V3: C24.1, JP11.2, R65.1, R75.2, R77.1, R80.2, U4.15, U4.17
3.3V4: C31.1, JP14.2, R85.1, R95.2, R97.1, R100.2, U5.15, U5.17
3.3V5: C38.1, JP17.2, R105.1, R115.2, R117.1, R120.2, U6.15, U6.17
3.3V6: C45.1, JP20.2, R125.1, R135.2, R137.1, R140.2, U7.15, U7.17
3.3V7: C52.1, JP23.2, R145.1, R155.2, R157.1, R160.2, U8.15, U8.17
3.3V8: C59.1, JP26.2, R165.1, R175.2, R177.1, R180.2, U9.15, U9.17
GND: C5.2, C7.2, JP3.1, R14.1, R19.1, SJ4.1, U1.16, U1.PAD
GND1: C9.2, C10.2, JP5.1, R32.1, R39.1, SJ1.1, U2.16, U2.PAD
GND2: C16.2, C17.2, JP8.1, R52.1, R59.1, SJ2.1, U3.16, U3.PAD
GND3: C23.2, C24.2, JP11.1, R72.1, R79.1, SJ3.1, U4.16, U4.PAD
GND4: C30.2, C31.2, JP14.1, R92.1, R99.1, SJ5.1, U5.16, U5.PAD
GND5: C37.2, C38.2, JP17.1, R112.1, R119.1, SJ6.1, U6.16, U6.PAD
GND6: C44.2, C45.2, JP20.1, R132.1, R139.1, SJ7.1, U7.16, U7.PAD
GND7: C51.2, C52.2, JP23.1, R152.1, R159.1, SJ8.1, U8.16, U8.PAD
GND8: C58.2, C59.2, JP26.1, R172.1, R179.1, SJ9.1, U9.16, U9.PAD
LA: JP1.2, JP2.RING, R1.1, R3.1
LA1: JP4.RING, JP6.2, R21.1, R29.1
LA2: JP7.RING, JP9.2, R41.1, R49.1
LA3: JP10.RING, JP12.2, R61.1, R69.1
LA4: JP13.RING, JP15.2, R81.1, R89.1
LA5: JP16.RING, JP18.2, R101.1, R109.1
LA6: JP19.RING, JP21.2, R121.1, R129.1
LA7: JP22.RING, JP24.2, R141.1, R149.1
LA8: JP25.RING, JP27.2, R161.1, R169.1
LO+: JP3.5, U1.12
LO+1: JP5.5, U2.12
LO+2: JP8.5, U3.12
LO+3: JP11.5, U4.12
LO+4: JP14.5, U5.12
LO+5: JP17.5, U6.12
LO+6: JP20.5, U7.12
LO+7: JP23.5, U8.12
LO+8: JP26.5, U9.12
LO-: JP3.4, U1.11
LO-1: JP5.4, U2.11
LO-2: JP8.4, U3.11
LO-3: JP11.4, U4.11
LO-4: JP14.4, U5.11
LO-5: JP17.4, U6.11
LO-6: JP20.4, U7.11
LO-7: JP23.4, U8.11
LO-8: JP26.4, U9.11
unnamed: R3.2, U1.2
unnamed: R4.2, U1.3
unnamed: C3.2, R7.2, U1.7
unnamed: C4.2, R11.1, U1.20
unnamed: C7.1, R10.2, R14.2, U1.18
unnamed: D1.A, R16.1
unnamed: R8.1, R9.2, U1.9
unnamed: R6.2, R13.1, U1.19
unnamed: C1.2, R6.1, R7.1
unnamed: D1.C, SJ4.2
unnamed: R19.2, R20.1, U1.14
unnamed: R21.2, U2.2
unnamed: C4.1, U1.1
unnamed: R11.2, R12.1, R13.2
unnamed: R22.2, U2.3
unnamed: C6.1, R12.2, R18.2, U1.6
unnamed: C2.1, U1.4
unnamed: C2.2, R5.1, U1.5
unnamed: C14.2, R23.2, U2.7
unnamed: R1.2, R2.2, R17.2, R18.1
unnamed: C12.2, R24.1, U2.20
unnamed: C9.1, R25.2, R32.2, U2.18
unnamed: R26.2, R27.1, U2.9
unnamed: C12.1, U2.1
unnamed: R24.2, R30.1, R31.2
unnamed: C11.1, R30.2, R38.2, U2.6
unnamed: C8.1, U2.4
unnamed: C13.2, R23.1, R33.1
unnamed: C8.2, R34.1, U2.5
unnamed: R31.1, R33.2, U2.19
unnamed: R28.2, R29.2, R37.2, R38.1
unnamed: D2.A, R36.1
unnamed: D2.C, SJ1.2
unnamed: R39.2, R40.1, U2.14
unnamed: R41.2, U3.2
unnamed: R42.2, U3.3
unnamed: C21.2, R43.2, U3.7
unnamed: C19.2, R44.1, U3.20
unnamed: C16.1, R45.2, R52.2, U3.18
unnamed: R46.2, R47.1, U3.9
unnamed: C19.1, U3.1
unnamed: R44.2, R50.1, R51.2
unnamed: C18.1, R50.2, R58.2, U3.6
unnamed: C15.1, U3.4
unnamed: C20.2, R43.1, R53.1
unnamed: C15.2, R54.1, U3.5
unnamed: R51.1, R53.2, U3.19
unnamed: R48.2, R49.2, R57.2, R58.1
unnamed: D3.A, R56.1
unnamed: D3.C, SJ2.2
unnamed: R59.2, R60.1, U3.14
unnamed: R61.2, U4.2
unnamed: R62.2, U4.3
unnamed: C28.2, R63.2, U4.7
unnamed: C26.2, R64.1, U4.20
unnamed: C23.1, R65.2, R72.2, U4.18
unnamed: R66.2, R67.1, U4.9
unnamed: C26.1, U4.1
unnamed: R64.2, R70.1, R71.2
unnamed: C25.1, R70.2, R78.2, U4.6
unnamed: C22.1, U4.4
unnamed: C27.2, R63.1, R73.1
unnamed: C22.2, R74.1, U4.5
unnamed: R71.1, R73.2, U4.19
unnamed: R68.2, R69.2, R77.2, R78.1
unnamed: D4.A, R76.1
unnamed: D4.C, SJ3.2
unnamed: R79.2, R80.1, U4.14
unnamed: R81.2, U5.2
unnamed: R82.2, U5.3
unnamed: C35.2, R83.2, U5.7
unnamed: C33.2, R84.1, U5.20
unnamed: C30.1, R85.2, R92.2, U5.18
unnamed: R86.2, R87.1, U5.9
unnamed: C33.1, U5.1
unnamed: R84.2, R90.1, R91.2
unnamed: C32.1, R90.2, R98.2, U5.6
unnamed: C29.1, U5.4
unnamed: C34.2, R83.1, R93.1
unnamed: C29.2, R94.1, U5.5
unnamed: R91.1, R93.2, U5.19
unnamed: R88.2, R89.2, R97.2, R98.1
unnamed: D5.A, R96.1
unnamed: D5.C, SJ5.2
unnamed: R99.2, R100.1, U5.14
unnamed: R101.2, U6.2
unnamed: R102.2, U6.3
unnamed: C42.2, R103.2, U6.7
unnamed: C40.2, R104.1, U6.20
unnamed: C37.1, R105.2, R112.2, U6.18
unnamed: R106.2, R107.1, U6.9
unnamed: C40.1, U6.1
unnamed: R104.2, R110.1, R111.2
unnamed: C39.1, R110.2, R118.2, U6.6
unnamed: C36.1, U6.4
unnamed: C41.2, R103.1, R113.1
unnamed: C36.2, R114.1, U6.5
unnamed: R111.1, R113.2, U6.19
unnamed: R108.2, R109.2, R117.2, R118.1
unnamed: D6.A, R116.1
unnamed: D6.C, SJ6.2
unnamed: R119.2, R120.1, U6.14
unnamed: R121.2, U7.2
unnamed: R122.2, U7.3
unnamed: C49.2, R123.2, U7.7
unnamed: C47.2, R124.1, U7.20
unnamed: C44.1, R125.2, R132.2, U7.18
unnamed: R126.2, R127.1, U7.9
unnamed: C47.1, U7.1
unnamed: R124.2, R130.1, R131.2
unnamed: C46.1, R130.2, R138.2, U7.6
unnamed: C43.1, U7.4
unnamed: C48.2, R123.1, R133.1
unnamed: C43.2, R134.1, U7.5
unnamed: R131.1, R133.2, U7.19
unnamed: R128.2, R129.2, R137.2, R138.1
unnamed: D7.A, R136.1
unnamed: D7.C, SJ7.2
unnamed: R139.2, R140.1, U7.14
unnamed: R141.2, U8.2
unnamed: R142.2, U8.3
unnamed: C56.2, R143.2, U8.7
unnamed: C54.2, R144.1, U8.20
unnamed: C51.1, R145.2, R152.2, U8.18
unnamed: R146.2, R147.1, U8.9
unnamed: C54.1, U8.1
unnamed: R144.2, R150.1, R151.2
unnamed: C53.1, R150.2, R158.2, U8.6
unnamed: C50.1, U8.4
unnamed: C55.2, R143.1, R153.1
unnamed: C50.2, R154.1, U8.5
unnamed: R151.1, R153.2, U8.19
unnamed: R148.2, R149.2, R157.2, R158.1
unnamed: D8.A, R156.1
unnamed: D8.C, SJ8.2
unnamed: R159.2, R160.1, U8.14
unnamed: R161.2, U9.2
unnamed: R162.2, U9.3
unnamed: C63.2, R163.2, U9.7
unnamed: C61.2, R164.1, U9.20
unnamed: C58.1, R165.2, R172.2, U9.18
unnamed: R166.2, R167.1, U9.9
unnamed: C61.1, U9.1
unnamed: R164.2, R170.1, R171.2
unnamed: C60.1, R170.2, R178.2, U9.6
unnamed: C57.1, U9.4
unnamed: C62.2, R163.1, R173.1
unnamed: C57.2, R174.1, U9.5
unnamed: R171.1, R173.2, U9.19
unnamed: R168.2, R169.2, R177.2, R178.1
unnamed: D9.A, R176.1
unnamed: D9.C, SJ9.2
unnamed: R179.2, R180.1, U9.14
RA: JP1.3, JP2.SLEEVE, R2.1, R4.1
RA1: JP4.SLEEVE, JP6.3, R22.1, R28.1
RA2: JP7.SLEEVE, JP9.3, R42.1, R48.1
RA3: JP10.SLEEVE, JP12.3, R62.1, R68.1
RA4: JP13.SLEEVE, JP15.3, R82.1, R88.1
RA5: JP16.SLEEVE, JP18.3, R102.1, R108.1
RA6: JP19.SLEEVE, JP21.3, R122.1, R128.1
RA7: JP22.SLEEVE, JP24.3, R142.1, R148.1
RA8: JP25.SLEEVE, JP27.3, R162.1, R168.1
REFOUT: C3.1, C6.2, R8.2, U1.8
REFOUT1: C11.2, C14.1, R27.2, U2.8
REFOUT2: C18.2, C21.1, R47.2, U3.8
REFOUT3: C25.2, C28.1, R67.2, U4.8
REFOUT4: C32.2, C35.1, R87.2, U5.8
REFOUT5: C39.2, C42.1, R107.2, U6.8
REFOUT6: C46.2, C49.1, R127.2, U7.8
REFOUT7: C53.2, C56.1, R147.2, U8.8
REFOUT8: C60.2, C63.1, R167.2, U9.8
RL: JP1.1, JP2.TIP, R5.2
RL1: JP4.TIP, JP6.1, R34.2
RL2: JP7.TIP, JP9.1, R54.2
RL3: JP10.TIP, JP12.1, R74.2
RL4: JP13.TIP, JP15.1, R94.2
RL5: JP16.TIP, JP18.1, R114.2
RL6: JP19.TIP, JP21.1, R134.2
RL7: JP22.TIP, JP24.1, R154.2
RL8: JP25.TIP, JP27.1, R174.2
SDN: JP3.6, R15.1, U1.13
SDN1: JP5.6, R35.1, U2.13
SDN2: JP8.6, R55.1, U3.13
SDN3: JP11.6, R75.1, U4.13
SDN4: JP14.6, R95.1, U5.13
SDN5: JP17.6, R115.1, U6.13
SDN6: JP20.6, R135.1, U7.13
SDN7: JP23.6, R155.1, U8.13
SDN8: JP26.6, R175.1, U9.13
SIGNAL_OUT: C1.1, JP3.3, R9.1, R16.2, U1.10
SIGNAL_OUT1: C13.1, JP5.3, R26.1, R36.2, U2.10
SIGNAL_OUT2: C20.1, JP8.3, R46.1, R56.2, U3.10
SIGNAL_OUT3: C27.1, JP11.3, R66.1, R76.2, U4.10
SIGNAL_OUT4: C34.1, JP14.3, R86.1, R96.2, U5.10
SIGNAL_OUT5: C41.1, JP17.3, R106.1, R116.2, U6.10
SIGNAL_OUT6: C48.1, JP20.3, R126.1, R136.2, U7.10
SIGNAL_OUT7: C55.1, JP23.3, R146.1, R156.2, U8.10
SIGNAL_OUT8: C62.1, JP26.3, R166.1, R176.2, U9.10

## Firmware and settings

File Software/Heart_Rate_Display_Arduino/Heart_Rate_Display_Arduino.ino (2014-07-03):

/******************************************************************************
Heart_Rate_Display.ino
Demo Program for AD8232 Heart Rate sensor.
Casey Kuhns @ SparkFun Electronics
6/27/2014
https://github.com/sparkfun/AD8232_Heart_Rate_Monitor

The AD8232 Heart Rate sensor is a low cost EKG/ECG sensor.  This example shows
how to create an ECG with real time display.  The display is using Processing.
This sketch is based heavily on the Graphing Tutorial provided in the Arduino
IDE. http://www.arduino.cc/en/Tutorial/Graph

Resources:
This program requires a Processing sketch to view the data in real time.

Development environment specifics:
	IDE: Arduino 1.0.5
	Hardware Platform: Arduino Pro 3.3V/8MHz
	AD8232 Heart Monitor Version: 1.0

This code is beerware. If you see me (or any other SparkFun employee) at the
local pub, and you've found our code helpful, please buy us a round!

Distributed as-is; no warranty is given.
******************************************************************************/

void setup() {
  // initialize the serial communication:
  Serial.begin(9600);
  pinMode(10, INPUT); // Setup for leads off detection LO +
  pinMode(11, INPUT); // Setup for leads off detection LO -

}

void loop() {
  
  if((digitalRead(10) == 1)||(digitalRead(11) == 1)){
    Serial.println('!');
  }
  else{
    // send the value of analog input 0:
      Serial.println(analogRead(A0));
  }
  //Wait for a bit to keep serial data from saturating
  delay(1);
}

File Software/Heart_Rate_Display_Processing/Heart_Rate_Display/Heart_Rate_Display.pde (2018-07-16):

/******************************************************************************
Heart_Rate_Display.ino
Demo Program for AD8232 Heart Rate sensor.
Casey Kuhns @ SparkFun Electronics
6/27/2014
https://github.com/sparkfun/AD8232_Heart_Rate_Monitor

The AD8232 Heart Rate sensor is a low cost EKG/ECG sensor.  This example shows
how to create an ECG with real time display.  The display is using Processing.
This sketch is based heavily on the Graphing Tutorial provided in the Arduino
IDE. http://www.arduino.cc/en/Tutorial/Graph

Resources:
This program requires a Processing sketch to view the data in real time.

Development environment specifics:
	IDE: Arduino 1.0.5
	Hardware Platform: Arduino Pro 3.3V/8MHz
	AD8232 Heart Monitor Version: 1.0

This code is beerware. If you see me (or any other SparkFun employee) at the
local pub, and you've found our code helpful, please buy us a round!

Distributed as-is; no warranty is given.
******************************************************************************/

import processing.serial.*;

Serial myPort;        // The serial port
int xPos = 1;         // horizontal position of the graph
float height_old = 0;
float height_new = 0;
float inByte = 0;
int BPM = 0;
int beat_old = 0;
float[] beats = new float[500];  // Used to calculate average BPM
int beatIndex;
float threshold = 620.0;  //Threshold at which BPM calculation occurs
boolean belowThreshold = true;
PFont font;


void setup () {
  // set the window size:
  size(1000, 400);        

  // List all the available serial ports
  println(Serial.list());
  // Open whatever port is the one you're using.
  myPort = new Serial(this, Serial.list()[2], 9600);
  // don't generate a serialEvent() unless you get a newline character:
  myPort.bufferUntil('\n');
  // set inital background:
  background(0xff);
  font = createFont("Ariel", 12, true);
}


void draw () {
     //Map and draw the line for new data point
     inByte = map(inByte, 0, 1023, 0, height);
     height_new = height - inByte; 
     line(xPos - 1, height_old, xPos, height_new);
     height_old = height_new;
    
      // at the edge of the screen, go back to the beginning:
      if (xPos >= width) {
        xPos = 0;
        background(0xff);
      } 
      else {
        // increment the horizontal position:
        xPos++;
      }
      
      // draw text for BPM periodically
      if (millis() % 128 == 0){
        fill(0xFF);
        rect(0, 0, 200, 20);
        fill(0x00);
        text("BPM: " + inByte, 15, 10);
      }
}


void serialEvent (Serial myPort) 
{
  // get the ASCII string:
  String inString = myPort.readStringUntil('\n');

  if (inString != null) 
  {
    // trim off any whitespace:
    inString = trim(inString);

    // If leads off detection is true notify with blue line
    if (inString.equals("!")) 
    { 
      stroke(0, 0, 0xff); //Set stroke to blue ( R, G, B)
      inByte = 512;  // middle of the ADC range (Flat Line)
    }
    // If the data is good let it through
    else 
    {
      stroke(0xff, 0, 0); //Set stroke to red ( R, G, B)
      inByte = float(inString); 
      
      // BPM calculation check
      if (inByte > threshold && belowThreshold == true)
      {
        calculateBPM();
        belowThreshold = false;
      }
      else if(inByte < threshold)
      {
        belowThreshold = true;
      }
    }
  }
}
  
void calculateBPM () 
{  
  int beat_new = millis();    // get the current millisecond
  int diff = beat_new - beat_old;    // find the time between the last two beats
  float currentBPM = 60000 / diff;    // convert to beats per minute
  beats[beatIndex] = currentBPM;  // store to array to convert the average
  float total = 0.0;
  for (int i = 0; i < 500; i++){
    total += beats[i];
  }
  BPM = int(total / 500);
  beat_old = beat_new;
  beatIndex = (beatIndex + 1) % 500;  // cycle through the array instead of using FIFO queue
  }

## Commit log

2013-11-15 Initial board design
    [AD8232_Heart_Rate_Monitor.brd, AD8232_Heart_Rate_Monitor.sch]
2013-11-21 Fixed silk and updated capacitors to appropriate sizes.
    [AD8232_Heart_Rate_Monitor.brd, AD8232_Heart_Rate_Monitor.sch]
2013-11-21 Fixed cap values
    [AD8232_Heart_Rate_Monitor.brd, AD8232_Heart_Rate_Monitor.sch]
2013-11-21 added name
    [AD8232_Heart_Rate_Monitor.brd]
2013-11-21 updated schematic in attempt to fix ERC errors
    [AD8232_Heart_Rate_Monitor.sch]
2013-11-21 Fixed file error
    [AD8232_Heart_Rate_Monitor.brd, AD8232_Heart_Rate_Monitor.sch]
2014-01-14 Changes made
    1. Added signal output pin
    2. Added pull-up resistor on shutdown pin to keep chip active by default.
    3. Moved some labels around to let everything fit
    4. fixed exposed vias.
    [AD8232_Heart_Rate_Monitor.brd, AD8232_Heart_Rate_Monitor.sch]
2014-01-14 Corrected chip orientation marker on board
    [AD8232_Heart_Rate_Monitor.brd, AD8232_Heart_Rate_Monitor.sch]
2014-01-21 added connectors for user leads, added led for some visual.
    [AD8232_Heart_Rate_Monitor.brd, AD8232_Heart_Rate_Monitor.sch]
2014-01-21 Updated components to match BOM
    [AD8232_Heart_Rate_Monitor.brd]
2014-01-21 changed jumpers to populatable jumpers makes for easy production changes
    [AD8232_Heart_Rate_Monitor.brd, AD8232_Heart_Rate_Monitor.sch]
2014-01-22 added matched traces
    [AD8232_Heart_Rate_Monitor.brd]
2014-03-25 Changed layout in attempt to remove noise. Changed resistor values to help remove DC offset.
    [AD8232_Heart_Rate_Monitor.brd, AD8232_Heart_Rate_Monitor.sch]
2014-05-02 Added fiducials
    [AD8232_Heart_Rate_Monitor.brd, AD8232_Heart_Rate_Monitor.sch]
2014-05-07 fixed Rev Numbers
    [AD8232_Heart_Rate_Monitor.brd, AD8232_Heart_Rate_Monitor.sch]
2014-05-08 fixed solder paste isssue with AD8232
    [AD8232_Heart_Rate_Monitor.brd, AD8232_Heart_Rate_Monitor.sch]
2014-05-12 created panel v10
    [AD8232_Heart_Rate_Monitor-Panel-v10.brd]
2014-06-27 added example code
    [Hear_Rate_Monitor_demo.fzz]
2014-07-03 cleaned up processing and arduino sketches
2014-07-09 fritzing parts worked on
    [Hear_Rate_Monitor_demo.fzz]
2014-07-15 General File cleanup
    [Hear_Rate_Monitor_demo.fzz, Heart_Rate_Monitor_demo.fzz]
2016-09-30 Adjusted paste on IC
    Note, I only adjusted the PRODUCTION panel file.
    Changed from single cirlce of paste under IC, to a window panned style.
    Reduced paste to 75% coverage on all outer pads on IC.
    Adjusted package lives in TEMP library in this repo.
    Also, kept original production BRD file for v10 for history.
    The new file "WINDOW_PANNED_PASTE" is intended to only be userd to buy a
    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
    [AD8232_Heart_Rate_Monitor-Panel-v10_WINDOW_PANNED_PASTE.brd]
2019-04-29 Corrected Fritzing Diagram
    [Heart_Rate_Monitor_demo.fzz]

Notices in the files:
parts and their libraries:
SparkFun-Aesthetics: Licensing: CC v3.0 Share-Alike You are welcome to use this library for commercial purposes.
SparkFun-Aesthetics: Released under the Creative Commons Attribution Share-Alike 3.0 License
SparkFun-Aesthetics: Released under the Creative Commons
